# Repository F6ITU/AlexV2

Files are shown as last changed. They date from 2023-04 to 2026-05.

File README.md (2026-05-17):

# Alexandrie_V2

Dual ADC OpenHPSDR frontend control board

  **Pour plus d'informations, reportez-vous au Wiki de la page [Alexandrie](https://github.com/F6ITU/Alexandrie)**
  **For more information, please refer to the [Alexandrie](https://github.com/F6ITU/Alexandrie) wiki page**

Kicad files

* Control board for Alexiares filter set driven by an Orion/OrionMK2/Anvelina SDR board with dual 16 bits ADC

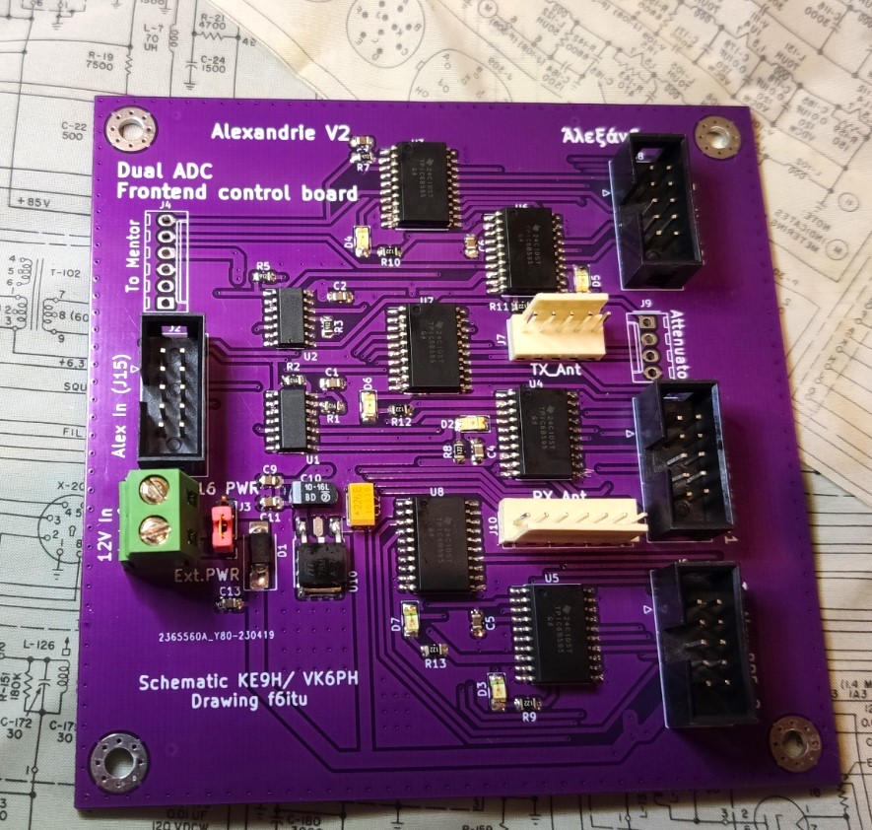
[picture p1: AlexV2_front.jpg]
aka "Alexandrie V2


This board supports the SPI "Alexiares" protocol (also called "J15") of 
the original Hermes SDR board designed by the OpenHPSDR group.

This second version drives a dual RX BPF filter. 
It also remains compatible with older versions of Alex (see assembly notes

As the third generation of Alexiares frontend is not sold by Apache but still under an open hardware licence, 
a new and more "modular" design was needed by many hams wishing to home-build a "Orion class" fontend

A common Gerber set of files will be used for both RX filters (one with a "RX2_GND" relay, one with a strap on the relay footprint)

TX filter depends on user's choice. The original 150W Alexiares lpf (https://github.com/F6ITU/Alexiares_LPF)
or LA2NI Zolotarev 600W LPF (https://github.com/LA2NI/Zolotarev-LPF)
This board could also be used with the new Aries ATU/Zolotarev lpf/Munin400 high power frontend

This work is protected by the TAPR Open Hardware Licence https://www.tapr.org/ohl.html
Original work by Graham Haddock, KE9H and Phil Harman, VK6APH.

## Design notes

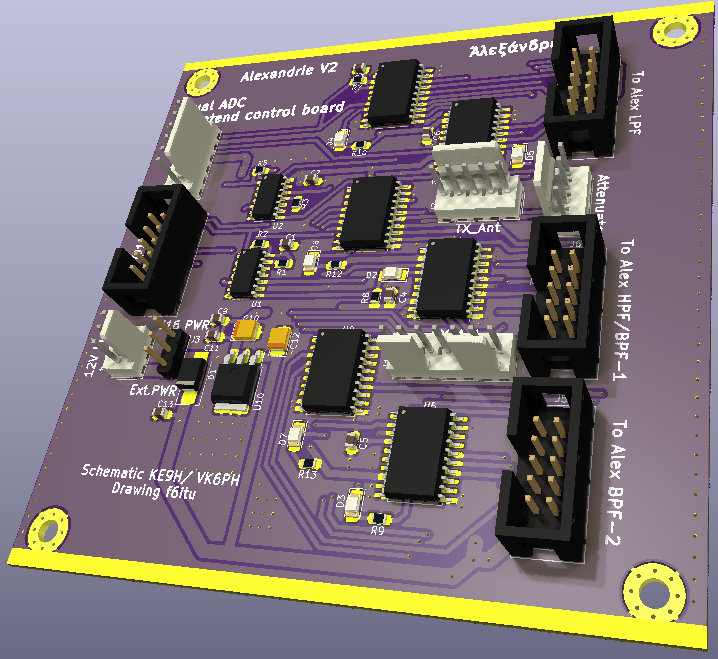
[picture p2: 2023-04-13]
Alexandrie_V2_up.png

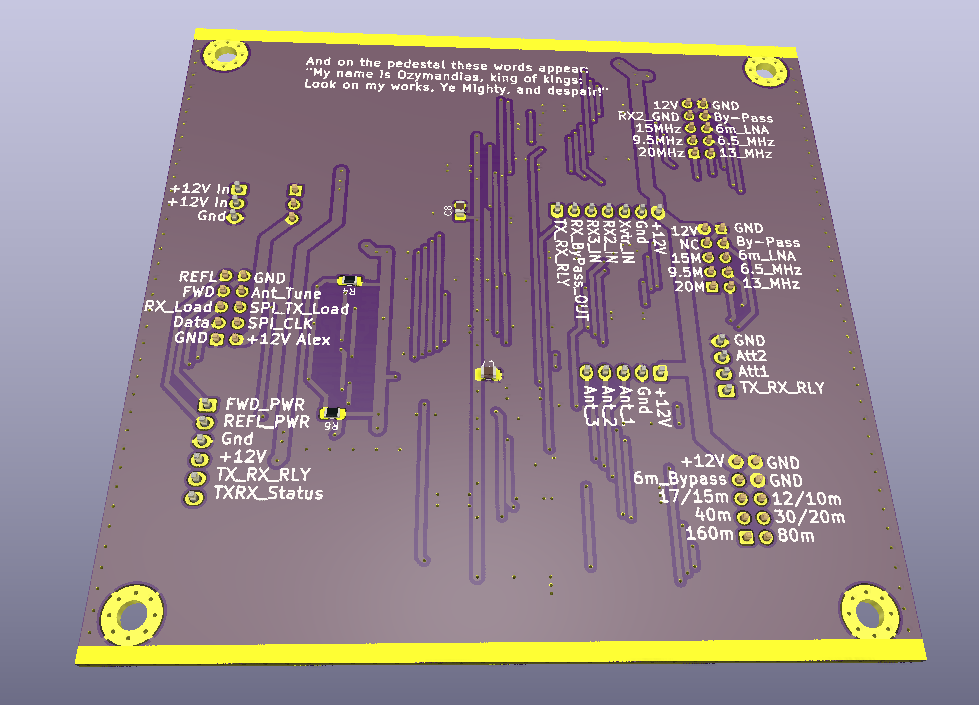
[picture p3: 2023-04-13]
Alexandrie_V2_dwn.png

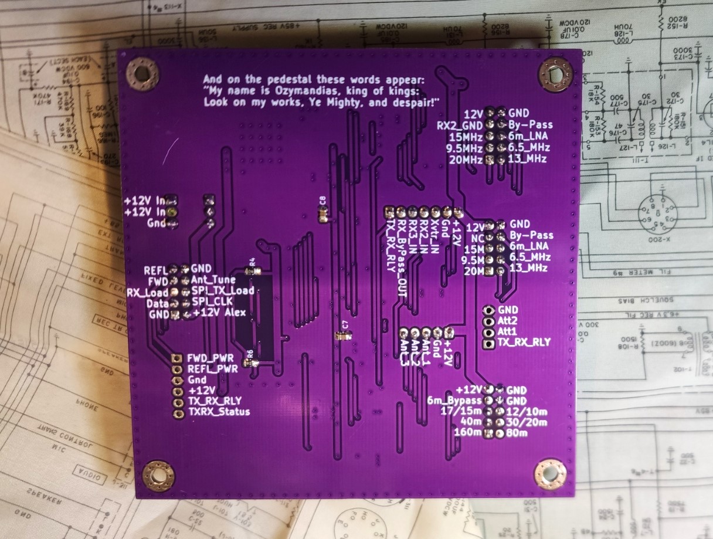
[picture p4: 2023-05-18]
AlexV2_back.jpg

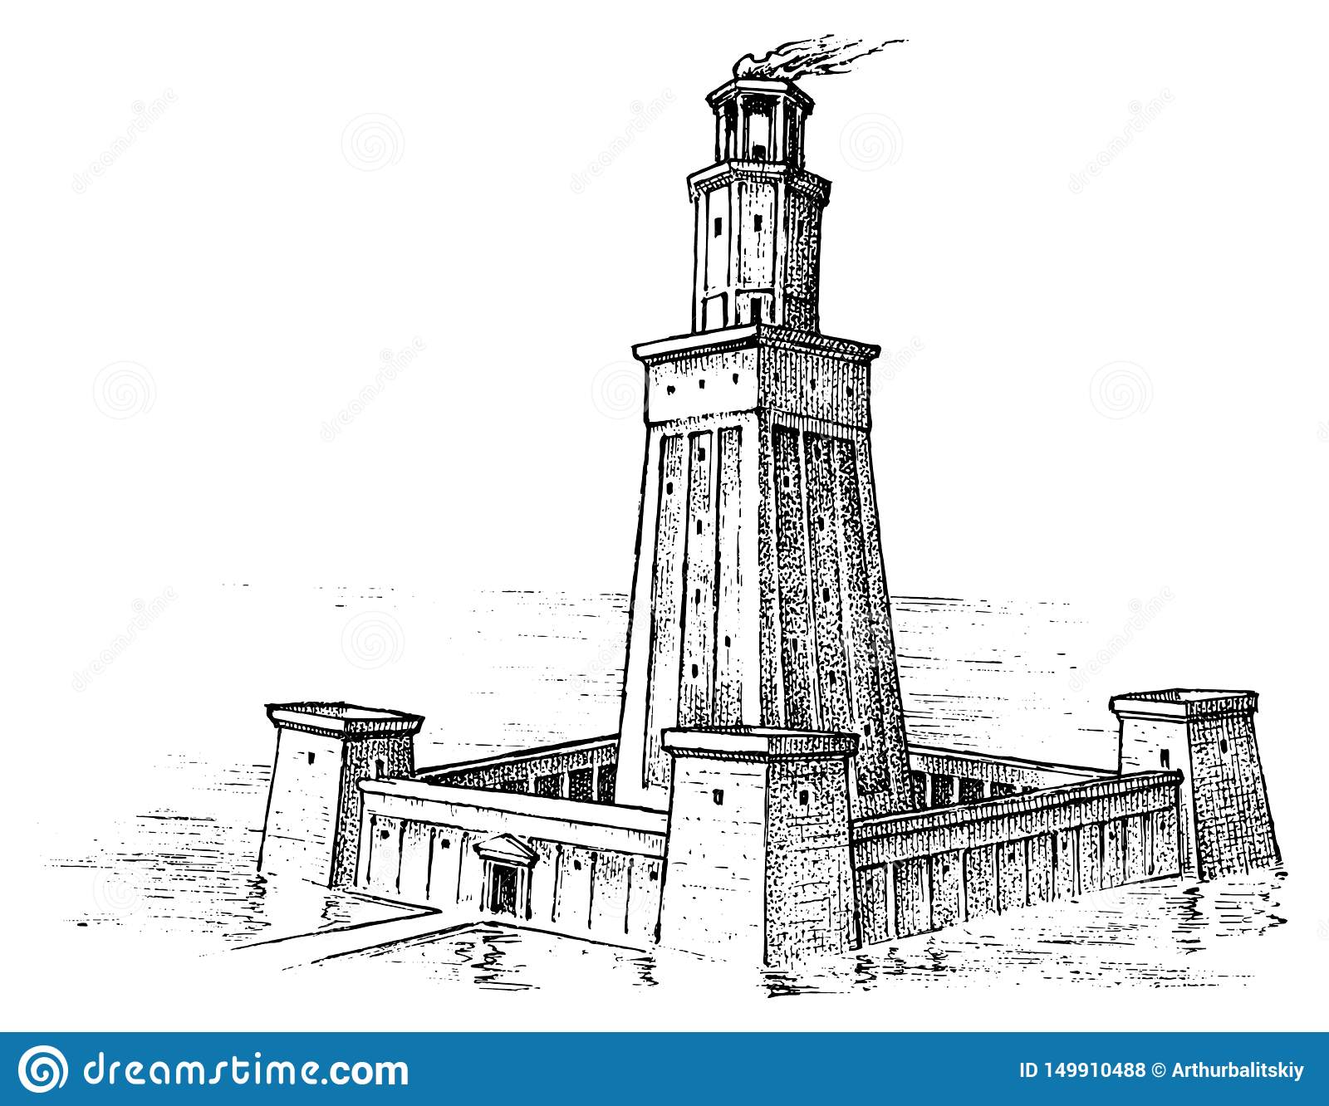
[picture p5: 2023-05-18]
alexandrie.jpg

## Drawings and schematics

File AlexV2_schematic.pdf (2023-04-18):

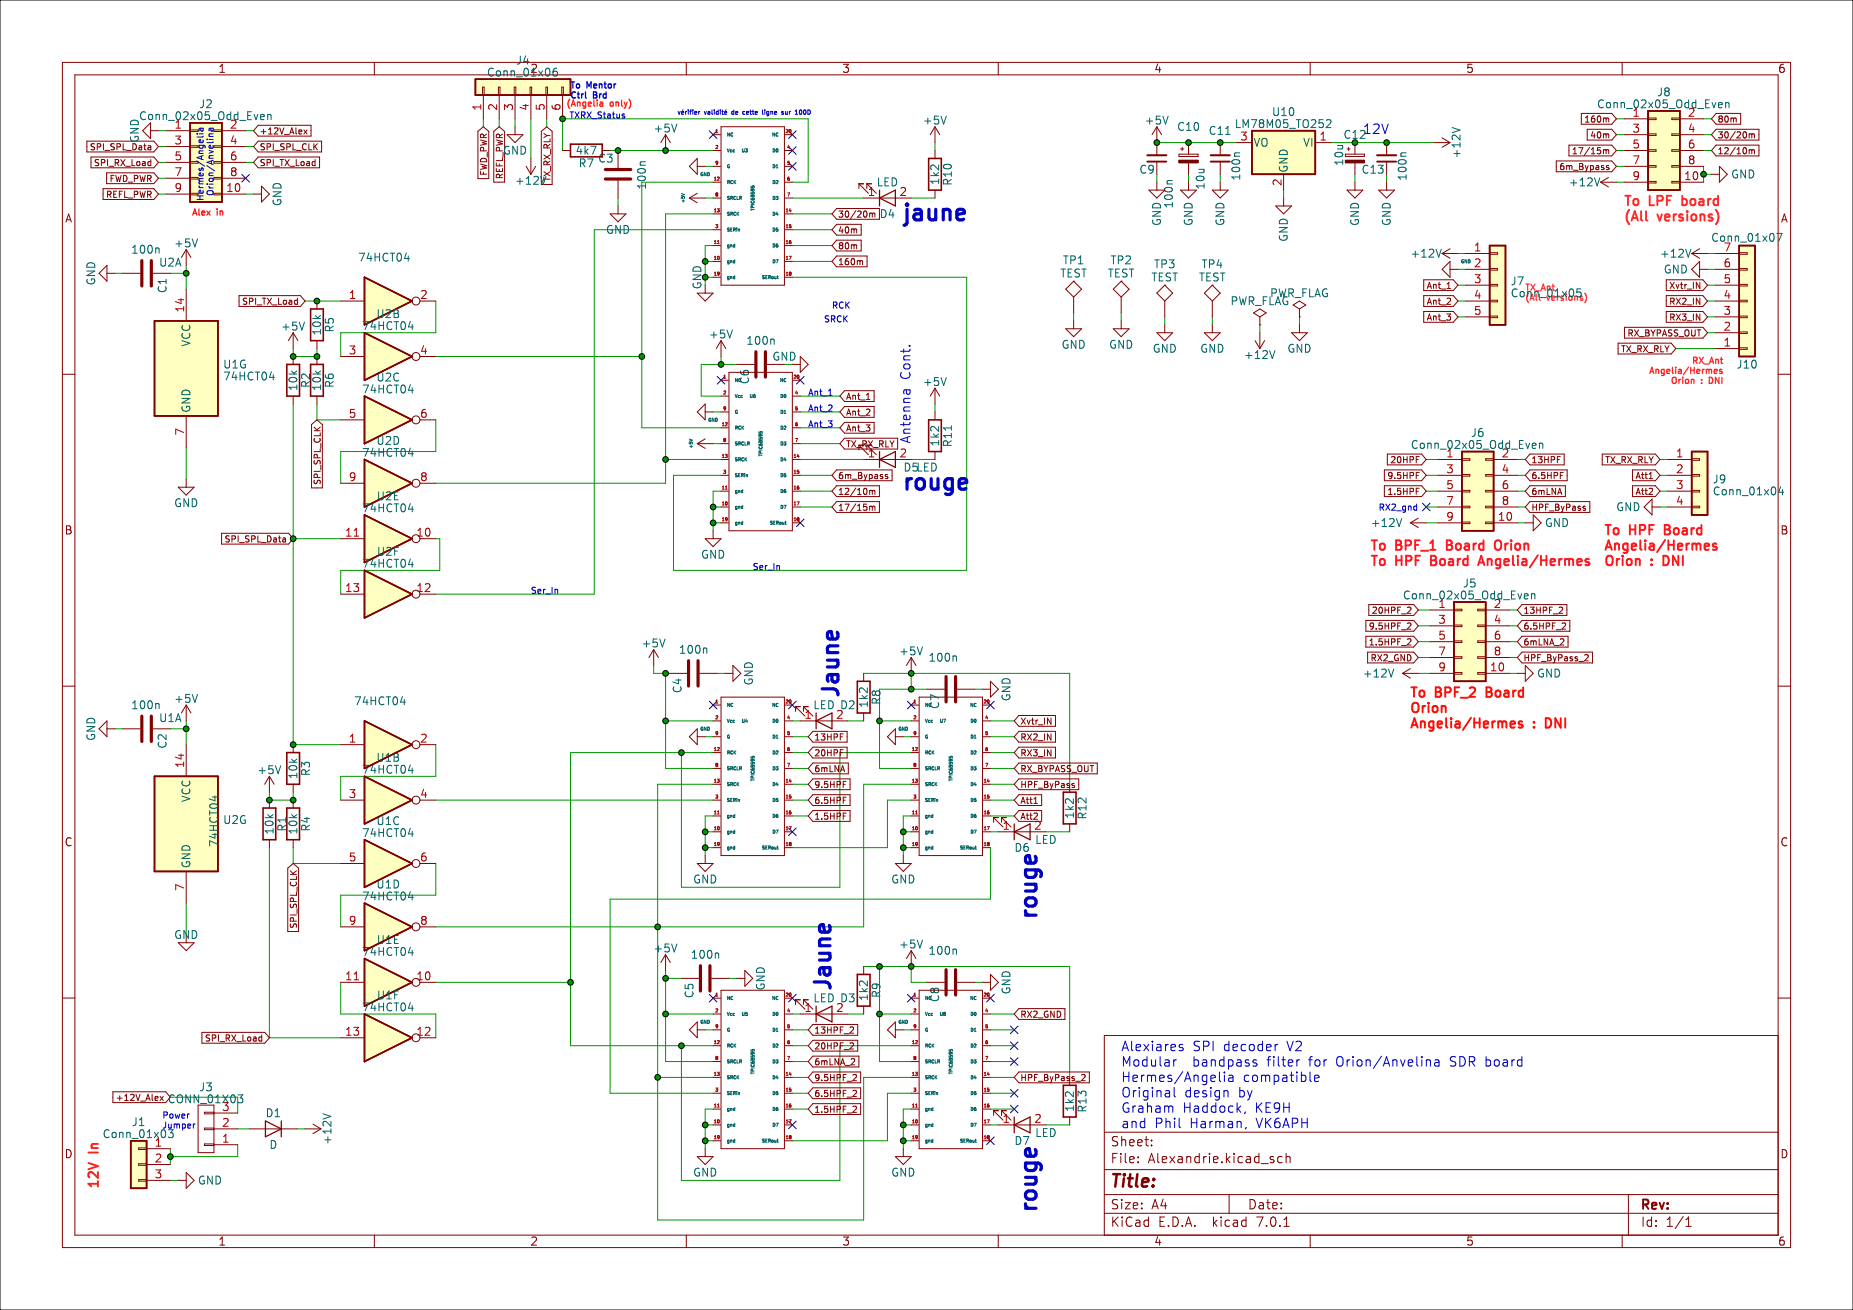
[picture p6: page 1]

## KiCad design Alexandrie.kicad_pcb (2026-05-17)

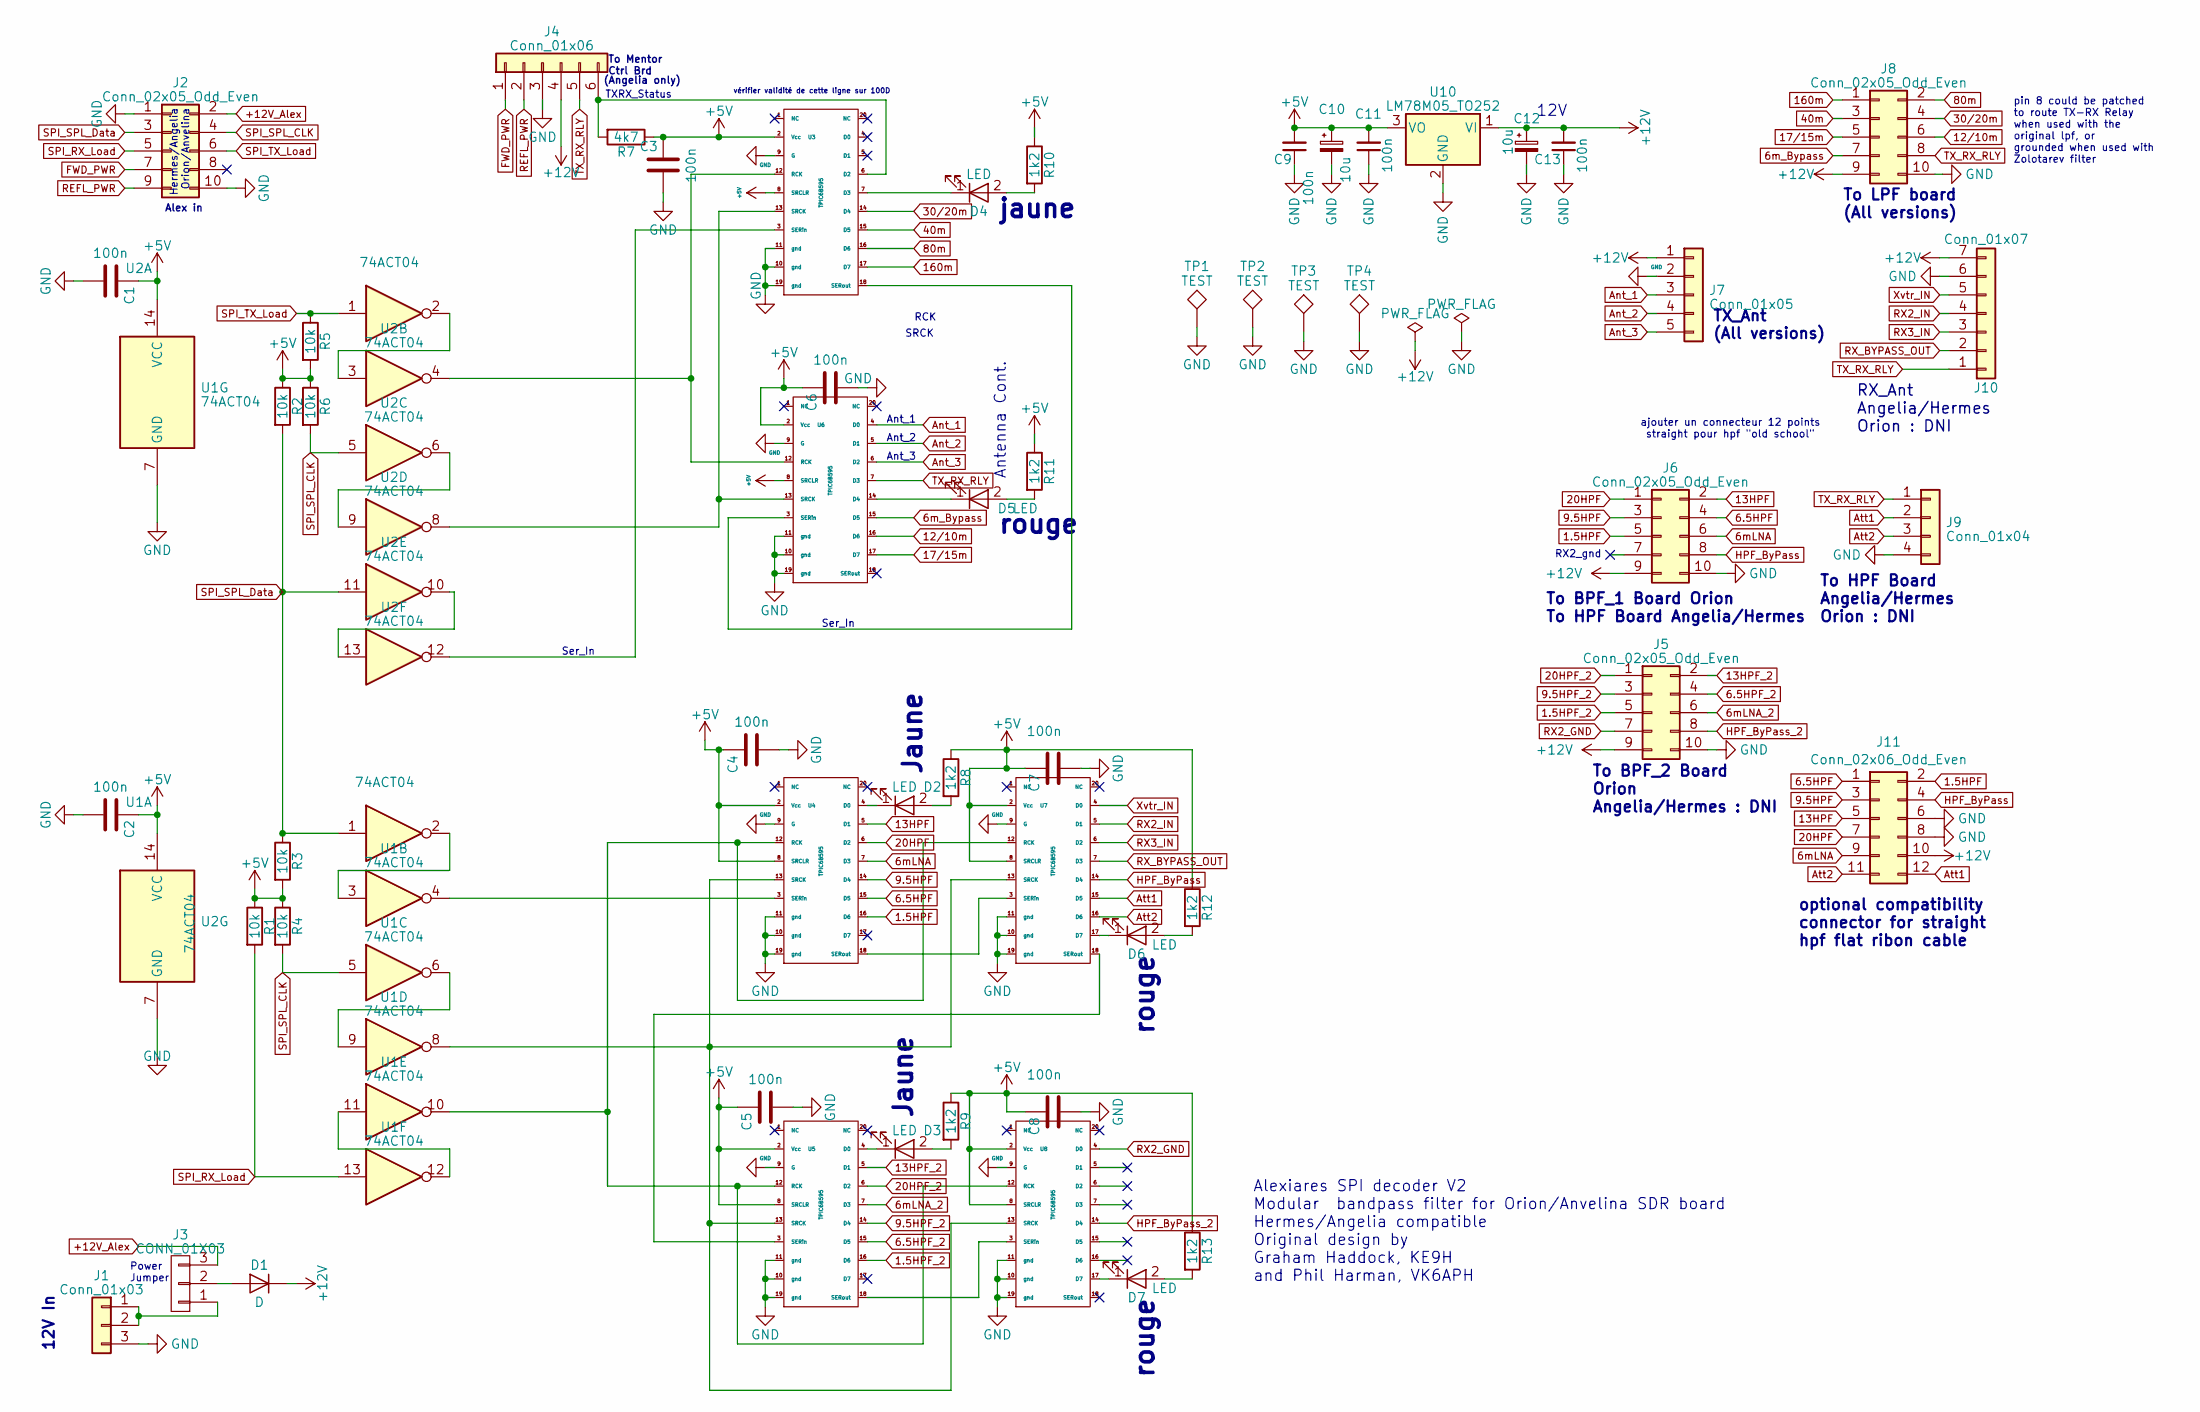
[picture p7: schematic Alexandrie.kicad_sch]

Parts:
C1, C2, C3, C4, C5, C6, C7, C8, C9, C11, C13: 100n; C_0805_2012Metric_Pad1.18x1.45mm_HandSolder
C10, C12: 10u; CP_EIA-3528-12_Kemet-T_Pad1.50x2.35mm_HandSolder
D1: D; D_SMB_Handsoldering
D2, D3, D4, D5, D6, D7: LED; LED_1206_3216Metric_Pad1.42x1.75mm_HandSolder
J1: Conn_01x03; Molex_KK-254_AE-6410-03A_1x03_P2.54mm_Vertical
J2, J5, J6, J8: Conn_02x05_Odd_Even; IDC-Header_2x05_P2.54mm_Vertical
J3: CONN_01X03; PinHeader_1x03_P2.54mm_Vertical
J4: Conn_01x06; Molex_KK-254_AE-6410-06A_1x06_P2.54mm_Vertical
J7: Conn_01x05; Molex_KK-254_AE-6410-05A_1x05_P2.54mm_Vertical
J9: Conn_01x04; Molex_KK-254_AE-6410-04A_1x04_P2.54mm_Vertical
J10: Conn_01x07; Molex_KK-254_AE-6410-07A_1x07_P2.54mm_Vertical
J11: Conn_02x06_Odd_Even; IDC-Header_2x06_P2.54mm_Vertical
R1, R2, R3, R4, R5, R6: 10k; R_0805_2012Metric_Pad1.20x1.40mm_HandSolder
R7: 4k7; R_0805_2012Metric_Pad1.20x1.40mm_HandSolder
R8, R9, R10, R11, R12, R13: 1k2; R_0805_2012Metric_Pad1.20x1.40mm_HandSolder
TP1, TP2, TP3, TP4: TEST; MountingHole_3.5mm_Pad_Via
U1, U2: 74ACT04; SOIC-14_3.9x8.7mm_P1.27mm
U3, U4, U5, U6, U7, U8: TPIC6B595; SOIC-20W_7.5x12.8mm_P1.27mm
U10: LM78M05_TO252; TO-252-3_TabPin2

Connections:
1.5HPF: J6.5, J11.2, U4.16 (D6)
1.5HPF_2: J5.5, U5.16 (D6)
6.5HPF: J6.4, J11.1, U4.15 (D5)
6.5HPF_2: J5.4, U5.15 (D5)
6mLNA: J6.6, J11.9, U4.7 (D3)
6mLNA_2: J5.6, U5.7 (D3)
6m_Bypass: J8.7, U6.15 (D5)
9.5HPF: J6.3, J11.3, U4.14 (D4)
9.5HPF_2: J5.3, U5.14 (D4)
12/10m: J8.6, U6.16 (D6)
13HPF: J6.2, J11.5, U4.5 (D1)
13HPF_2: J5.2, U5.5 (D1)
17/15m: J8.5, U6.17 (D7)
20HPF: J6.1, J11.7, U4.6 (D2)
20HPF_2: J5.1, U5.6 (D2)
30/20m: J8.4, U3.14 (D4)
40m: J8.3, U3.15 (D5)
80m: J8.2, U3.16 (D6)
160m: J8.1, U3.17 (D7)
+5V: C1.1, C2.1, C3.1, C4.1, C5.1, C6.1, C7.1, C8.1, C9.2, C10.1, C11.2, R1.1, R2.1, R3.2, R4.1, R5.2, R6.1, R7.1, R8.1, R9.1, R10.1, R11.1, R12.1, R13.1, U1.14 (VCC), U2.14 (VCC), U3.2 (Vcc), U3.8 (SRCLR), U4.2 (Vcc), U4.8 (SRCLR), U5.2 (Vcc), U5.8 (SRCLR), U6.2 (Vcc), U6.8 (SRCLR), U7.2 (Vcc), U7.8 (SRCLR), U8.2 (Vcc), U8.8 (SRCLR), U10.3 (VO)
+12V: C12.1, C13.2, D1.1 (K), J4.4, J5.9, J6.9, J7.1, J8.9, J10.7, J11.10, U10.1 (VI)
+12V_Alex: J2.2, J3.3
Ant_1: J7.3, U6.4 (D0)
Ant_2: J7.4, U6.5 (D1)
Ant_3: J7.5, U6.6 (D2)
Att1: J9.2, J11.12, U7.15 (D5)
Att2: J9.3, J11.11, U7.16 (D6)
FWD_PWR: J2.7, J4.1
GND: C1.2, C2.2, C3.2, C4.2, C5.2, C6.2, C7.2, C8.2, C9.1, C10.2, C11.1, C12.2, C13.1, J1.3, J2.1, J2.10, J4.3, J5.10, J6.10, J7.2, J8.10, J9.4, J10.6, J11.6, J11.8, TP1.1, TP2.1, TP3.1, TP4.1, U1.7 (GND), U2.7 (GND), U3.9 (G), U3.10 (gnd), U3.11 (gnd), U3.19 (gnd), U4.9 (G), U4.10 (gnd), U4.11 (gnd), U4.19 (gnd), U5.9 (G), U5.10 (gnd), U5.11 (gnd), U5.19 (gnd), U6.9 (G), U6.10 (gnd), U6.11 (gnd), U6.19 (gnd), U7.9 (G), U7.10 (gnd), U7.11 (gnd), U7.19 (gnd), U8.9 (G), U8.10 (gnd), U8.11 (gnd), U8.19 (gnd), U10.2 (GND)
HPF_ByPass: J6.8, J11.4, U7.14 (D4)
HPF_ByPass_2: J5.8, U8.14 (D4)
unnamed: D1.2 (A), J3.2
unnamed: D2.2 (A), R8.2
unnamed: D2.1 (K), U4.4 (D0)
unnamed: D3.2 (A), R9.2
unnamed: D3.1 (K), U5.4 (D0)
unnamed: D4.2 (A), R10.2
unnamed: D4.1 (K), U3.7 (D3)
unnamed: D5.2 (A), R11.2
unnamed: D5.1 (K), U6.14 (D4)
unnamed: D6.2 (A), R12.2
unnamed: D6.1 (K), U7.17 (D7)
unnamed: D7.2 (A), R13.2
unnamed: D7.1 (K), U8.17 (D7)
unnamed: J1.1, J1.2, J3.1
unnamed: J4.6, R7.2, U3.6 (D2)
unnamed: U1.2, U1.3
unnamed: U1.6, U1.9
unnamed: U1.11, U1.12
unnamed: U2.2, U2.3
unnamed: U2.6, U2.9
unnamed: U2.10, U2.13
unnamed: U2.4, U3.12 (RCK), U6.12 (RCK)
unnamed: U2.12, U3.3 (SERin)
unnamed: U3.18 (SERout), U6.3 (SERin)
unnamed: U2.8, U3.13 (SRCK), U6.13 (SRCK)
unnamed: U1.10, U4.12 (RCK), U5.12 (RCK), U7.12 (RCK), U8.12 (RCK)
unnamed: U1.4, U4.3 (SERin)
unnamed: U4.18 (SERout), U7.3 (SERin)
unnamed: U1.8, U4.13 (SRCK), U5.13 (SRCK), U7.13 (SRCK), U8.13 (SRCK)
unnamed: U5.3 (SERin), U7.18 (SERout)
unnamed: U5.18 (SERout), U8.3 (SERin)
REFL_PWR: J2.9, J4.2
RX2_GND: J5.7, U8.4 (D0)
RX2_IN: J10.4, U7.5 (D1)
RX3_IN: J10.3, U7.6 (D2)
RX_BYPASS_OUT: J10.2, U7.7 (D3)
SPI_RX_Load: J2.5, R1.2, U1.13
SPI_SPL_CLK: J2.4, R4.2, R6.2, U1.5, U2.5
SPI_SPL_Data: J2.3, R2.2, R3.1, U1.1, U2.11
SPI_TX_Load: J2.6, R5.1, U2.1
TX_RX_RLY: J4.5, J8.8, J9.1, J10.1, U6.7 (D3)
Xvtr_IN: J10.5, U7.4 (D0)

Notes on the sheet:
SRCK
To HPF Board Angelia/Hermes Orion : DNI
(Angelia only)
Jaune
Ant_1
Antenna Cont.
To BPF_2 Board Orion Angelia/Hermes : DNI
Ant_3
Power Jumper
jaune
rouge
TXRX_Status
optional compatibility connector for straight hpf flat ribon cable
ajouter un connecteur 12 points straight pour hpf "old school"
RCK
Ser_In
To BPF_1 Board Orion To HPF Board Angelia/Hermes
RX_Ant Angelia/Hermes Orion : DNI
Alexiares SPI decoder V2 Modular bandpass filter for Orion/Anvelina SDR board Hermes/Angelia compatible Original design by Graham Haddock, KE9H and Phil Harman, VK6APH
RX2_gnd
12V
TX_Ant (All versions)
12V In
Alex in
Hermes/Angelia Orion/Anvelina
pin 8 could be patched to route TX-RX Relay when used with the original lpf, or grounded when used with Zolotarev filter
vérifier validité de cette ligne sur 100D
To Mentor Ctrl Brd
Ant_2
To LPF board (All versions)
rouge

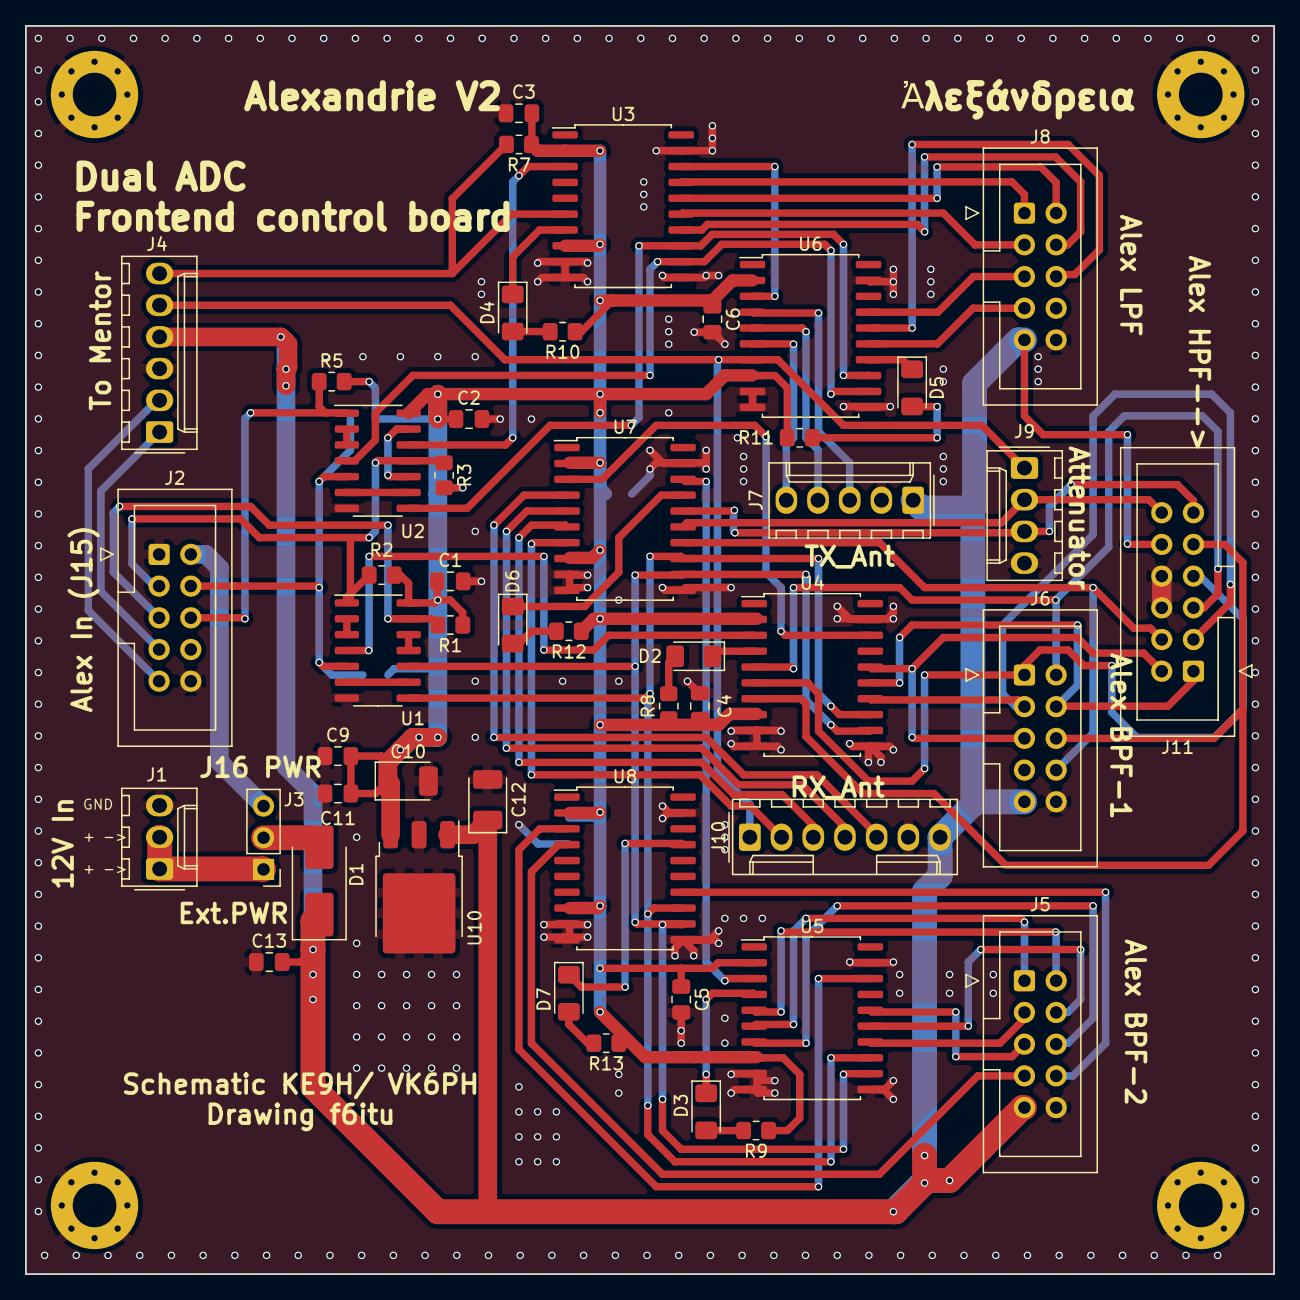
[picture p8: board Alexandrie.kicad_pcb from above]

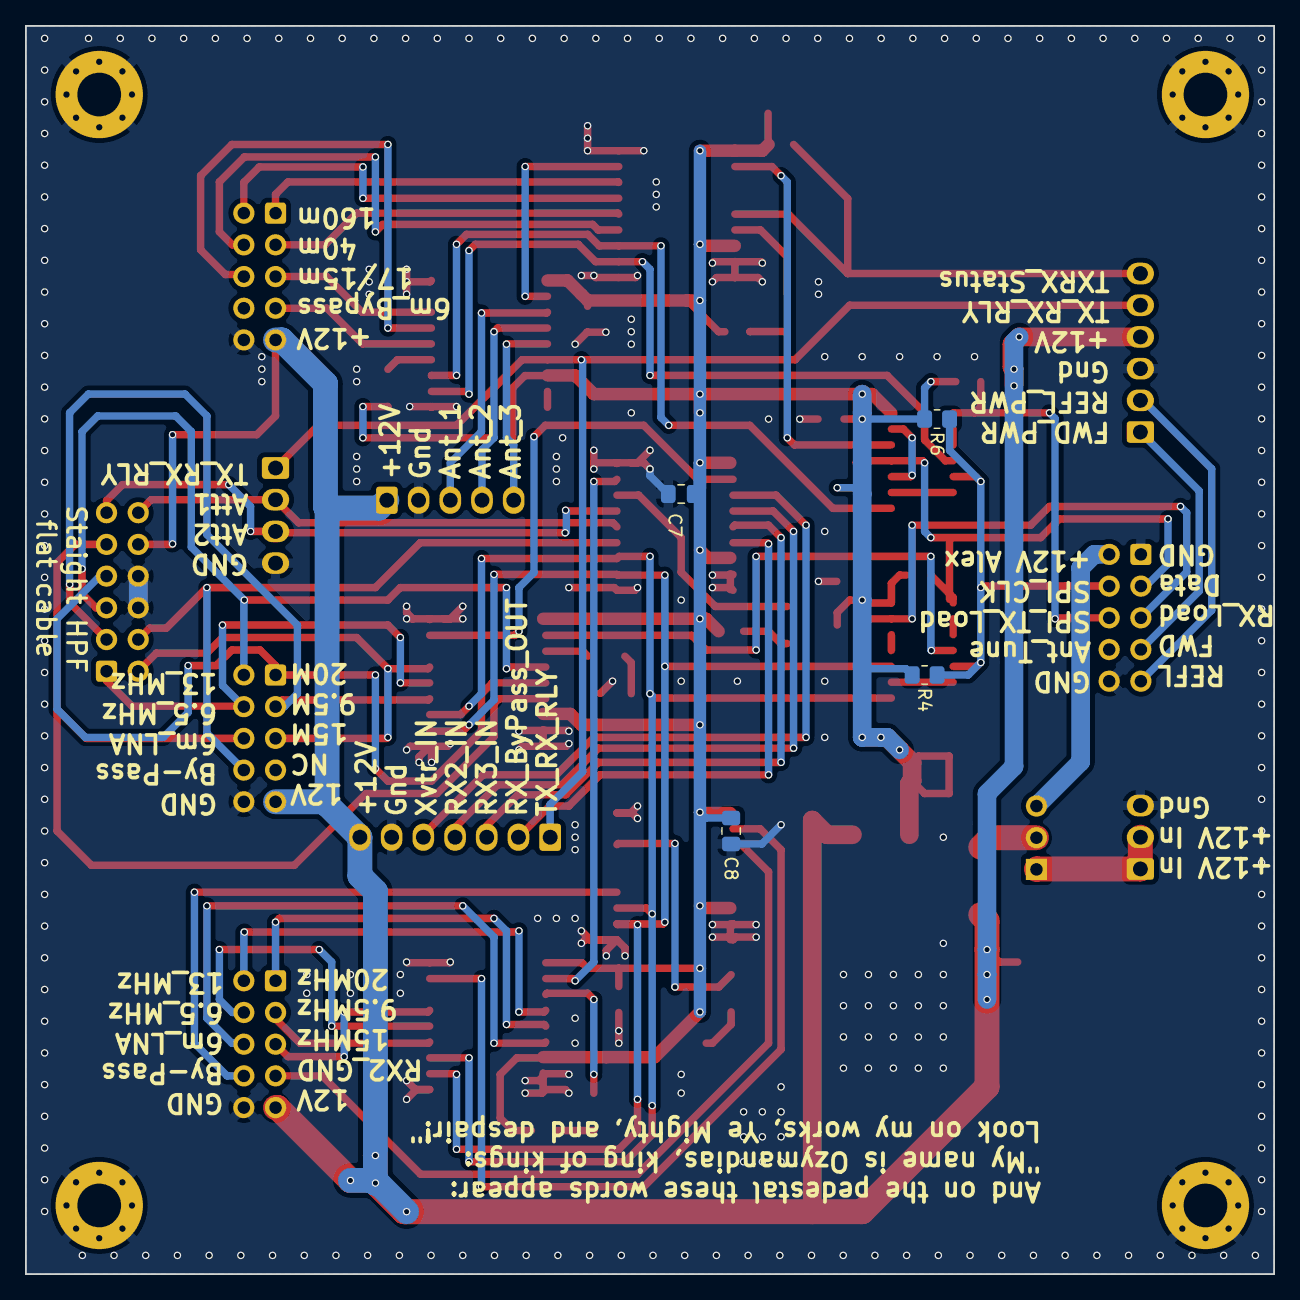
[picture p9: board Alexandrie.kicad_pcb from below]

Board: 2 copper layers, 100.0 x 100.0 mm, 57 parts (4 on the bottom side), 73 nets.

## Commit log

2023-04-12 initial design
    [Alexandrie.kicad_pcb, Alexandrie.kicad_sch, Alexandrie.sch]
2023-04-13 first RTM with silkmask
    [Alexandrie.kicad_pcb]
2023-04-13 DRC clean, iBom saved
    [Alexandrie.kicad_pcb, Alexandrie.kicad_sch]
2023-04-17 new readme, new ibom, new schematic pdf
2023-04-18 schematic pdf added
2023-05-18 minor chages, new iBom
    [Alexandrie-B_Cu.gbl, Alexandrie-B_Mask.gbs, Alexandrie-B_Paste.gbp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]
2026-05-17 kicad 10 update, new readme, new wiki link
    [Alexandrie-B_Cu.gbl, Alexandrie-B_Mask.gbs, Alexandrie-B_Paste.gbp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]
